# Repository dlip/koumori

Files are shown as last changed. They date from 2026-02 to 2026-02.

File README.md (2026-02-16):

# Koumori Keyboard

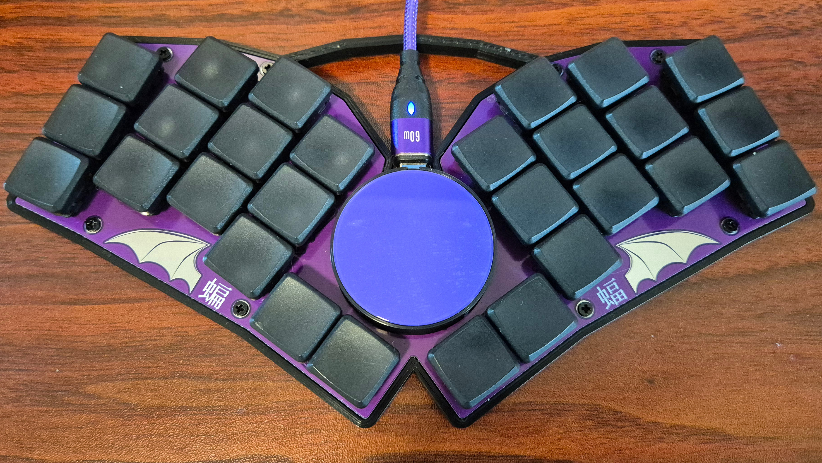
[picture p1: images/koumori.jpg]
Koumori


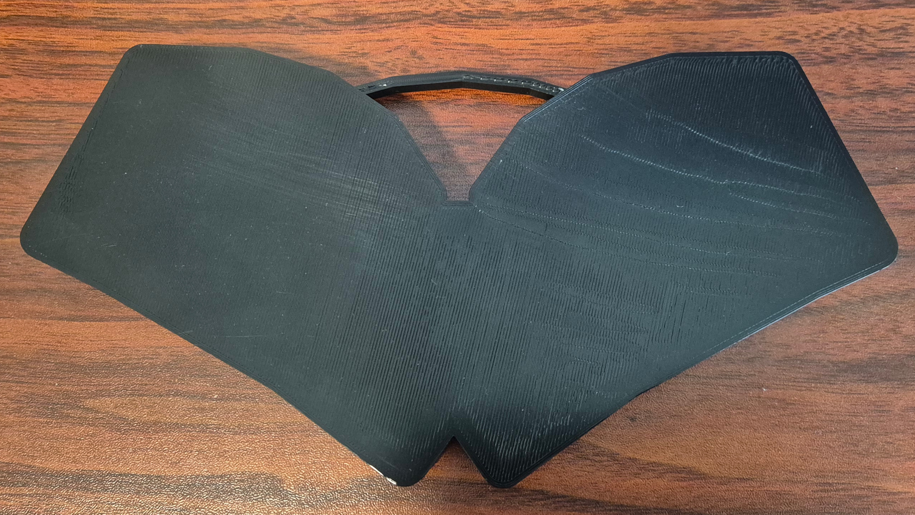
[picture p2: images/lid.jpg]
Lid


- Designed to be minimalistic and portable
- 28 keys (Using Engram with my [layout](https://github.com/dlip/qmk_firmware/blob/dlip/keyboards/dlip/koumori/keymaps/engram/README.md))
- Unibody design
- RP2040-Zero MCU
- Cirque 40mm trackpad with glass overlay
- Customizable layout with QMK Firmware
- Case with handle and magnetic lid
- PCB and case designed in [Ergogen](https://ergogen.xyz)
- Simple [build guide](./build.md) with no microscopic parts
- Name means the animal "bat" in Japanese
- Open source and free (GPL-3.0)

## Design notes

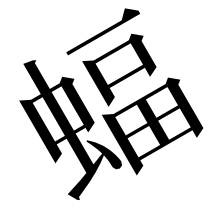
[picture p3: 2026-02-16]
kicad/footprints/text276.png

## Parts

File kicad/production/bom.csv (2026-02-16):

Designator | Footprint | Quantity | Value | LCSC Part #
D1, D10, D11, D12, D13, D14, D15, D16, D17, D18, D19, D2, D20, D21, D22, D23, D24, D25, D26, D27, D28, D3, D4, D5, D6, D7, D8, D9 | ComboDiode | 28
POINTING1 | Pointing-connector | 1
RP2040ZERO1 | RP2040-Zero | 1
S1, S10, S11, S12, S13, S14, S15, S16, S17, S18, S19, S2, S20, S21, S22, S23, S24, S25, S26, S27, S28, S3, S4, S5, S6, S7, S8, S9 | PG1350 | 28
_1, _10, _11, _2, _3, _4, _5, _6, _7, _8, _9 | MountingHole_2.2mm_M2_Pad_Via | 11

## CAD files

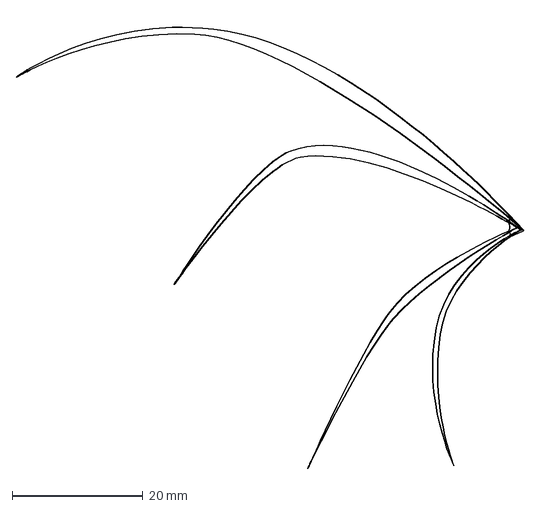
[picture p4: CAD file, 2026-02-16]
3d/wing.dxf
77.5 x 69.1 mm

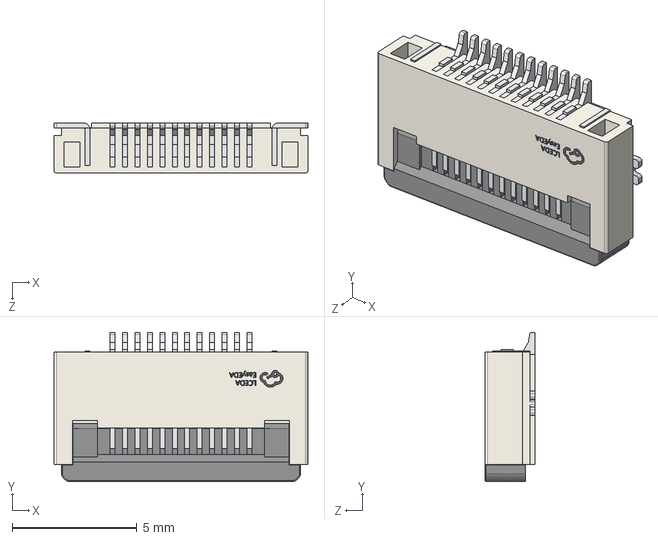
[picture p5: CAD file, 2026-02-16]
kicad/3dmodels/AFC01-S12FCC-00.step
10.2 x 6.00 x 2.01 mm

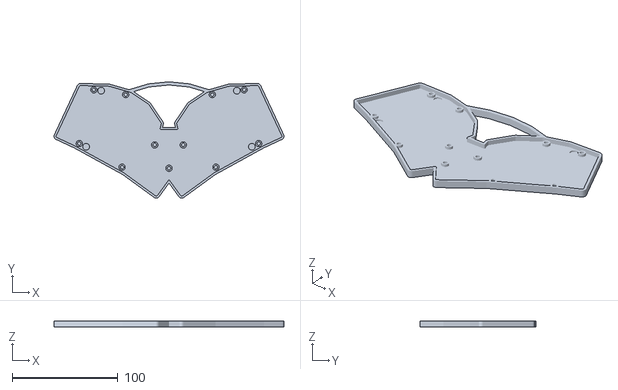
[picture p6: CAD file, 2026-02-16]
3d/case.stl
217.0 x 109.8 x 5.60

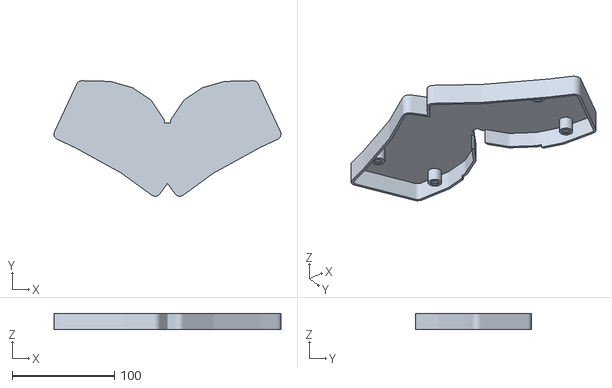
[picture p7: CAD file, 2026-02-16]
3d/lid.stl
221.6 x 112.8 x 16.0

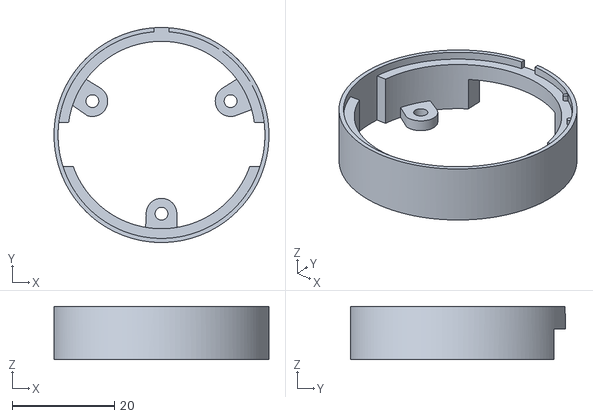
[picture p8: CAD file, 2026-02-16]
3d/cirque-mount.stl
42.0 x 42.0 x 10.4

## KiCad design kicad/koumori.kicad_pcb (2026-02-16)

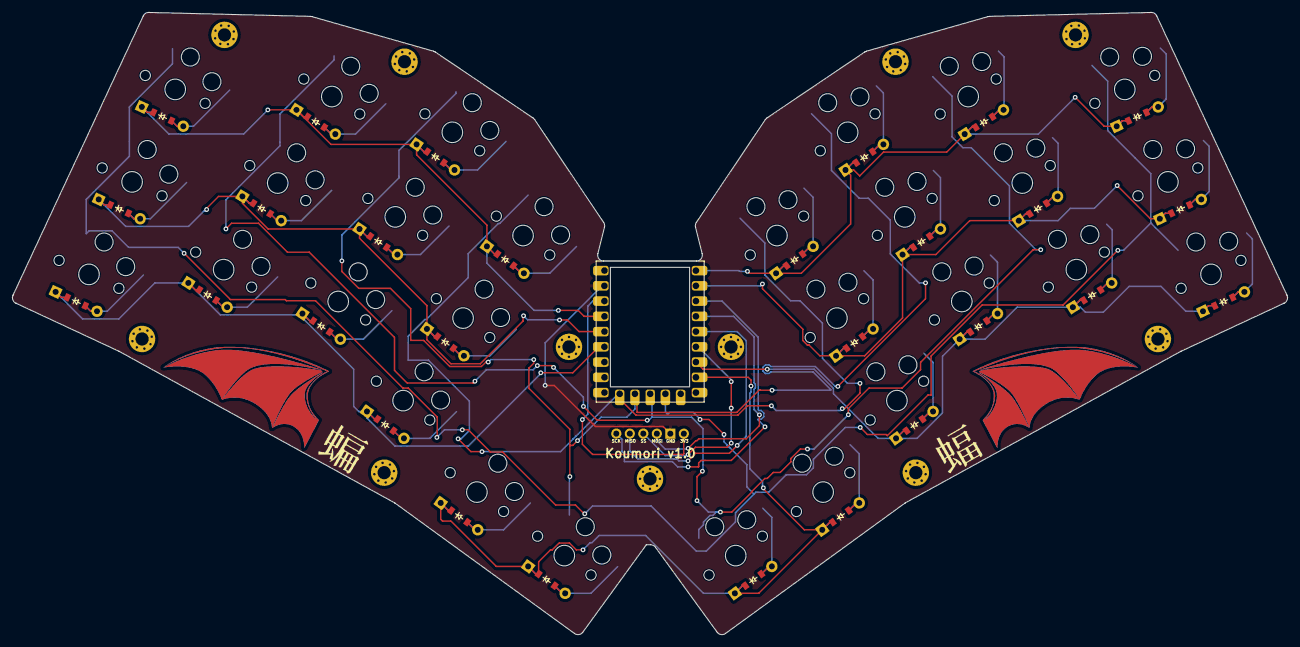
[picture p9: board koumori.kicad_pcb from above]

Board: 2 copper layers, 212.4 x 103.7 mm, 69 parts (0 on the bottom side), 45 nets.

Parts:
D1, D2, D3, D4, D5, D6, D7, D8, D9, D10, D11, D12, D13, D14, D15, D16, D17, D18, D19, D20, D21, D22, D23, D24, D25, D26, D27, D28: ComboDiode
Pointing1: Pointing-connector
RP2040Zero1: RP2040-Zero
S1, S2, S3, S4, S5, S6, S7, S8, S9, S10, S11, S12, S13, S14, S15, S16, S17, S18, S19, S20, S21, S22, S23, S24, S25, S26, S27, S28: PG1350
_1, _2, _3, _4, _5, _6, _7, _8, _9, _10, _11: MountingHole_2.2mm_M2_Pad_Via

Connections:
GND: Pointing1.5, RP2040Zero1.20
GP0: D17.1, D20.1, D23.1, D26.1, RP2040Zero1.1
GP1: D16.1, D19.1, D22.1, D25.1, RP2040Zero1.2
GP2: Pointing1.1, RP2040Zero1.3
GP3: Pointing1.4, RP2040Zero1.4
GP4: Pointing1.2, RP2040Zero1.5
GP5: Pointing1.3, RP2040Zero1.6
GP6: D15.1, D18.1, D21.1, D24.1, RP2040Zero1.7
GP7: D13.1, D14.1, D27.1, D28.1, RP2040Zero1.8
GP10: RP2040Zero1.11, S1.1, S2.1, S3.1, S15.1, S16.1, S17.1, S27.1
GP11: RP2040Zero1.12, S4.1, S5.1, S6.1, S18.1, S19.1, S20.1, S28.1
GP12: RP2040Zero1.13, S7.1, S8.1, S9.1, S14.1, S21.1, S22.1, S23.1
GP13: RP2040Zero1.14, S10.1, S11.1, S12.1, S13.1, S24.1, S25.1, S26.1
GP27: D1.1, D4.1, D7.1, D10.1, RP2040Zero1.18
GP28: D2.1, D5.1, D8.1, D11.1, RP2040Zero1.22
GP29: D3.1, D6.1, D9.1, D12.1, RP2040Zero1.23
P3V3: Pointing1.6, RP2040Zero1.21
index_bottom: D10.2, S10.2
index_middle: D11.2, S11.2
index_top: D12.2, S12.2
inner_top: D13.2, S13.2
middle_bottom: D7.2, S7.2
middle_middle: D8.2, S8.2
middle_top: D9.2, S9.2
mirror_index_bottom: D24.2, S24.2
mirror_index_middle: D25.2, S25.2
mirror_index_top: D26.2, S26.2
mirror_inner_top: D27.2, S27.2
mirror_middle_bottom: D21.2, S21.2
mirror_middle_middle: D22.2, S22.2
mirror_middle_top: D23.2, S23.2
mirror_outer_top: D28.2, S28.2
mirror_pinky_bottom: D15.2, S15.2
mirror_pinky_middle: D16.2, S16.2
mirror_pinky_top: D17.2, S17.2
mirror_ring_bottom: D18.2, S18.2
mirror_ring_middle: D19.2, S19.2
mirror_ring_top: D20.2, S20.2
outer_top: D14.2, S14.2
pinky_bottom: D1.2, S1.2
pinky_middle: D2.2, S2.2
pinky_top: D3.2, S3.2
ring_bottom: D4.2, S4.2
ring_middle: D5.2, S5.2
ring_top: D6.2, S6.2

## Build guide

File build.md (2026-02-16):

# Build

## BOM

| Name | Qty | Link |
| --- | --- | --- |
| PCB (kicad/production/koumori_v1.0.0.zip) | 1 | <https://jlcpcb.com/> |
| Cirque 40mm Trackpad TM040040-2024-302 with flat overlay | 1 | <https://au.mouser.com/ProductDetail/Cirque/TM040040-2024-302> |
| Choc v1 Switches | 28  | <https://keebd.com/products/ambients-silent-linear-nocturnal-choc-switches> |
| Choc v1 Keycaps | 28  | <https://chosfox.com/collections/cfx-keycaps/products/chocfox-cfx-choc-keycaps> |
| RP2040 Zero MCU | 1 | <https://www.aliexpress.com/item/1005007650325892.html> |
| 1N4148W diodes | 28  | <https://www.aliexpress.com/item/4000685043735.html> |
| Choc v1 Hot-Swap Socket (Low Profile) | 28  | <https://www.aliexpress.com/item/1005006625852715.html> Note: these ones had a slightly annoying to solder metal tab |
| M2 Screw 4mm | 8 | <https://www.aliexpress.com/item/4001248931159.html> |
| M2 Screw 6mm | 3 | <https://www.aliexpress.com/item/4001248931159.html> |
| M2 knurled insert nuts 3mm length 3.5mm OD | 11  | <https://www.aliexpress.com/item/1005008897571758.html> |
| Neodymium Magnets 6mm x 3mm | 8 | <https://www.aliexpress.com/item/1005010074888189.html> |
| Wire (30 AWG) | 1 | <https://www.aliexpress.com/item/1005007256968315.html> |
| Adhesive Vinyl Sheets | 1 | <https://www.aliexpress.com/item/1005009732820762.html> |
| 40mm Glass Smartwatch Screen Protector (**NOT** Galaxy Watch 40mm which is actually 36.5mm) | 1 | <https://www.aliexpress.com/item/1005007458477781.html> |
| USB-C Cable | 1 | <https://www.aliexpress.com/item/1005005931593343.html> |
| Blutak | 1 | |
| Superglue | 1 | |
| 3D Printed Case (3d/case.stl) | 1 | |
| 3D Printed Lid (3d/lid.stl) | 1 | |
| 3D Printed Cirque Mount (3d/cirque-mount.stl) | 1 | |

## Build

- Flash the firmware first to make sure your MCU is ok <https://github.com/dlip/qmk_firmware/tree/dlip/keyboards/dlip/koumori>
- Tin the left side of all the pads on the back (side containing the url)

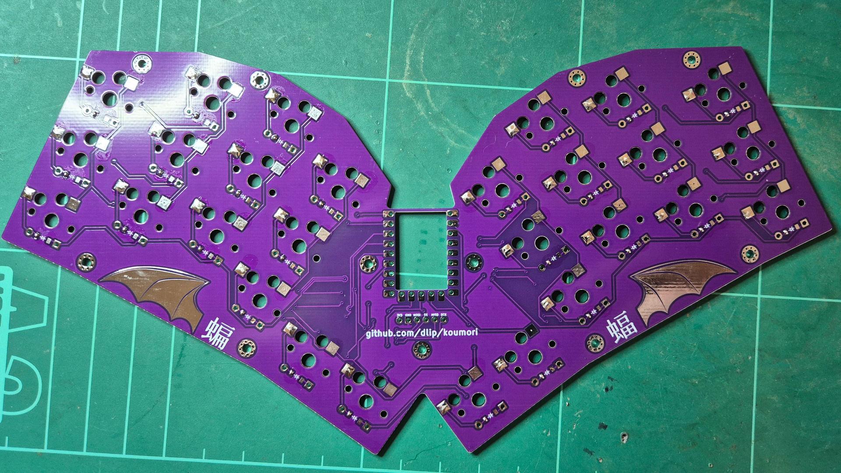
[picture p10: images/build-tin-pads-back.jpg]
Tin pads back


- Before soldering, note the correct direction of the diodes following the side with the line

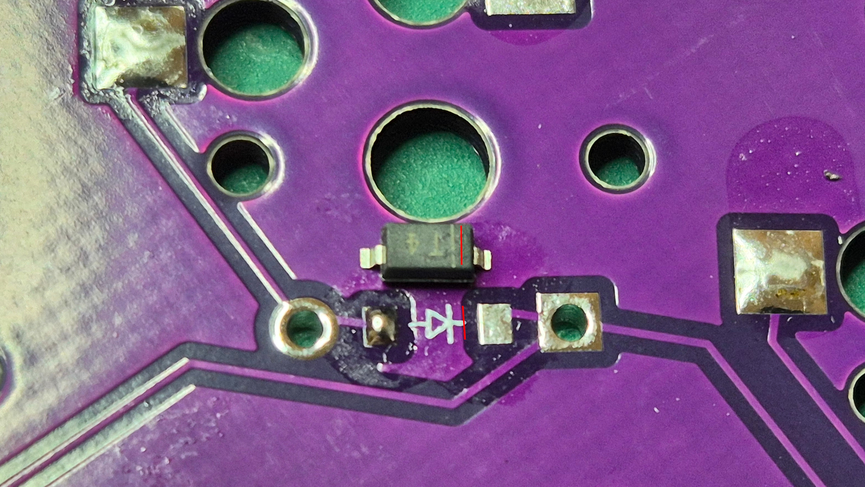
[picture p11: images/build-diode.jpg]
Diodes


- Solder the left side of the diodes and hot swap sockets, ensuring they are aligned, then solder the right sides. Note: I was short on hot swap sockets here, so some are missing

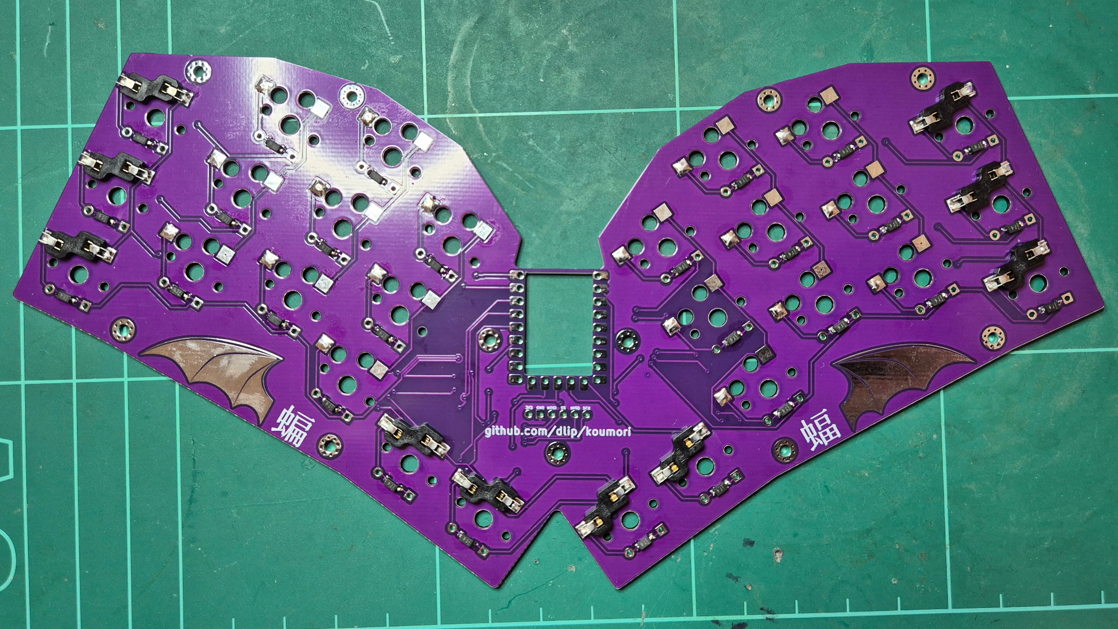
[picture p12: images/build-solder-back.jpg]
Solder Back


- Flip over to the front side
- Tin the pads for the MCU

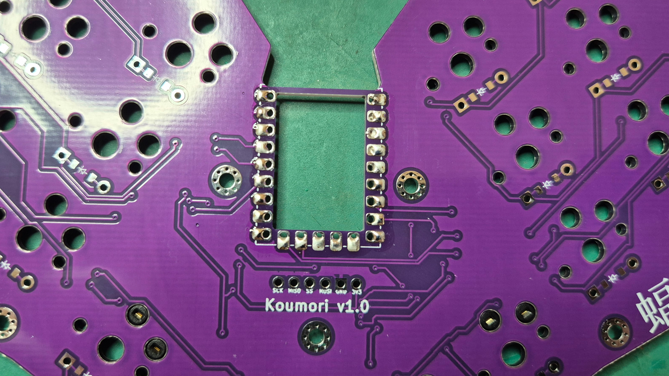
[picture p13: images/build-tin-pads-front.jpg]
Tin pads front


- Solder one pin on the MCU and ensure it is aligned perfectly
- Solder the pin on the opposite corner to ensure it won't move
- Solder the remaining pins

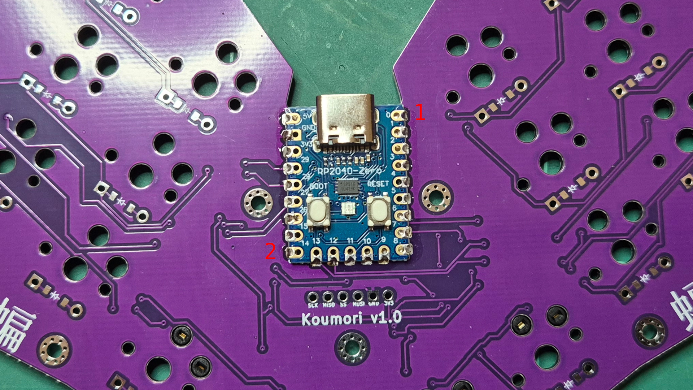
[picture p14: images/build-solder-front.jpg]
Solder front


- Peel off stock overlay from Cirque
- Stick glass protector to vinyl sheet
- Cut out using scissors and a X-Acto knife
- Stick on Cirque

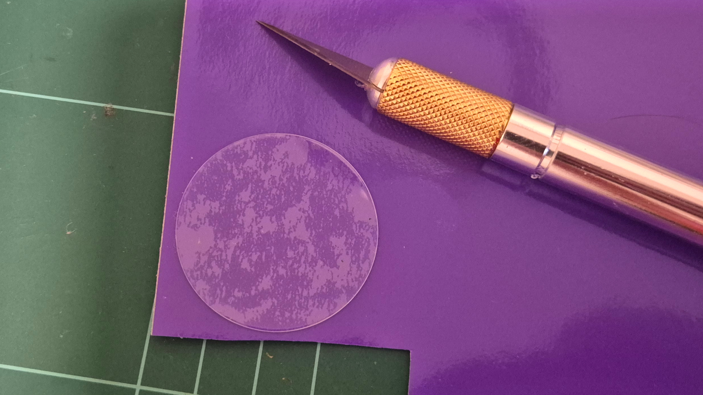
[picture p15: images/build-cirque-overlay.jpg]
Cirque overlay


- Solder Cirque using about 10 cm wire stripped at the ends using the following mapping
  - SCK -> SCK
  - MISO -> SO
  - SS -> SS
  - MOSI -> SI
  - GND -> GND
  - 3V3 -> VDD

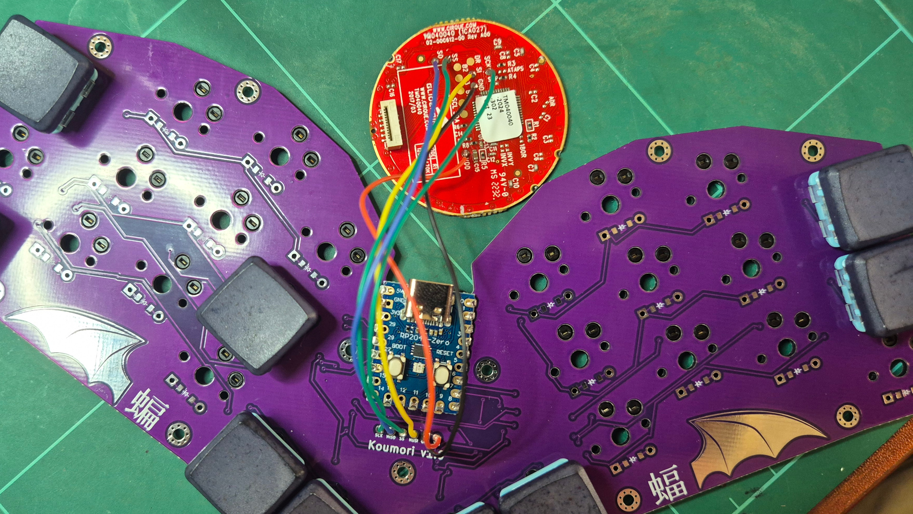
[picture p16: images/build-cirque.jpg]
Cirque


- Add switches and keycaps
- Connect USB and test everything is working
- Melt knurled nuts into base with soldering iron at around 180c
- Mark the side of the magnets you intend to point upwards
- Superglue magnets into base, ensuring your mark **IS** showing

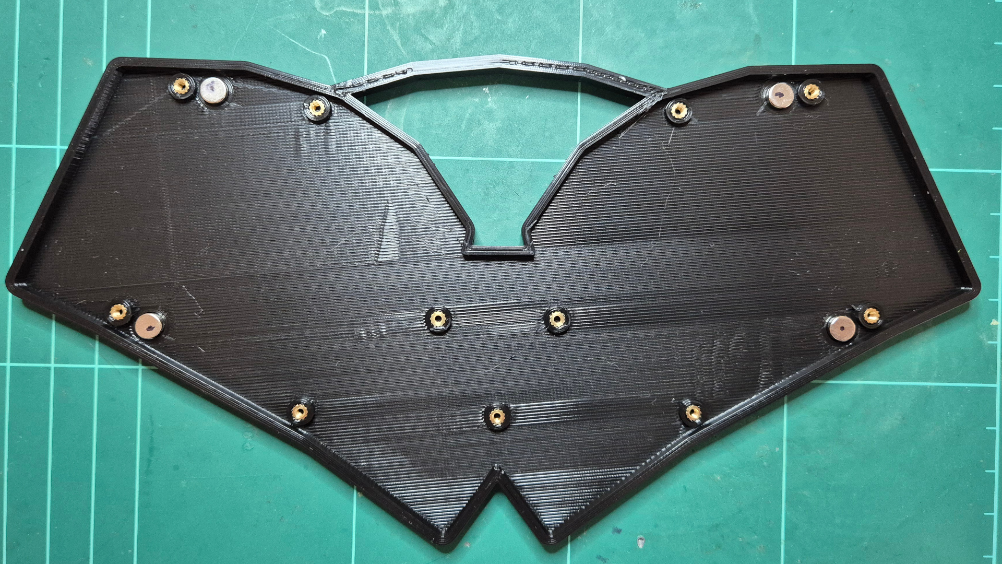
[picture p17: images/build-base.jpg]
Base


- Screw 3x6mm screws in the center region and 8x4mm in the remaining holes

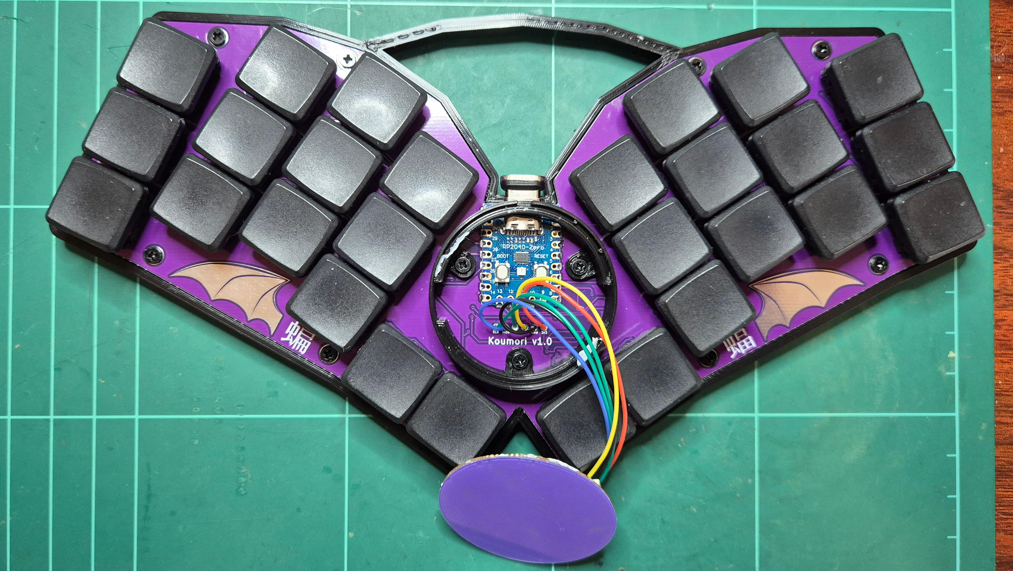
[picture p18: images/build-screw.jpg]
Screw


- Add rubber feet

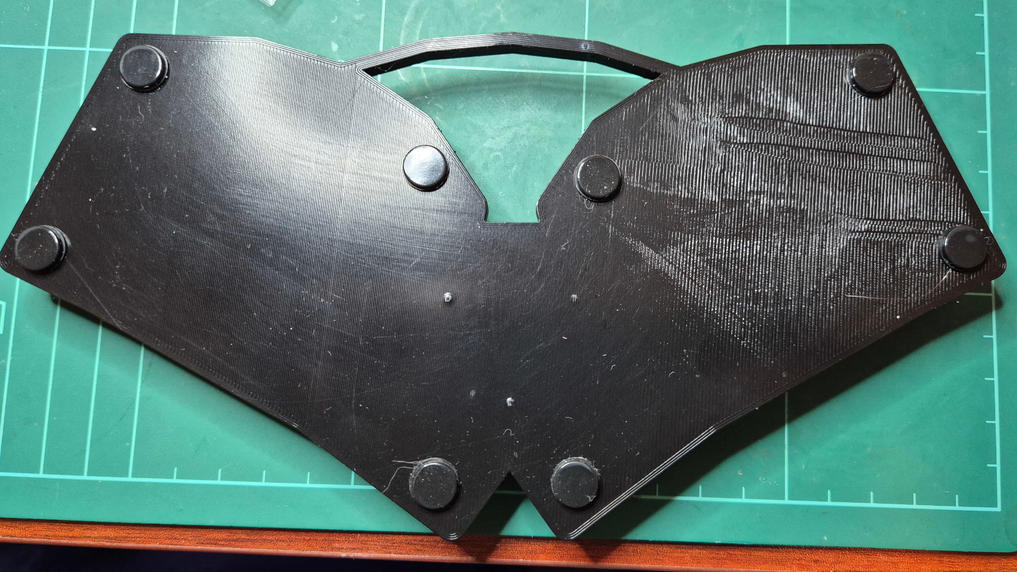
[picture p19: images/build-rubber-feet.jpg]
Rubber feet


- Superglue magnets into lid, ensuring your mark **IS NOT** showing

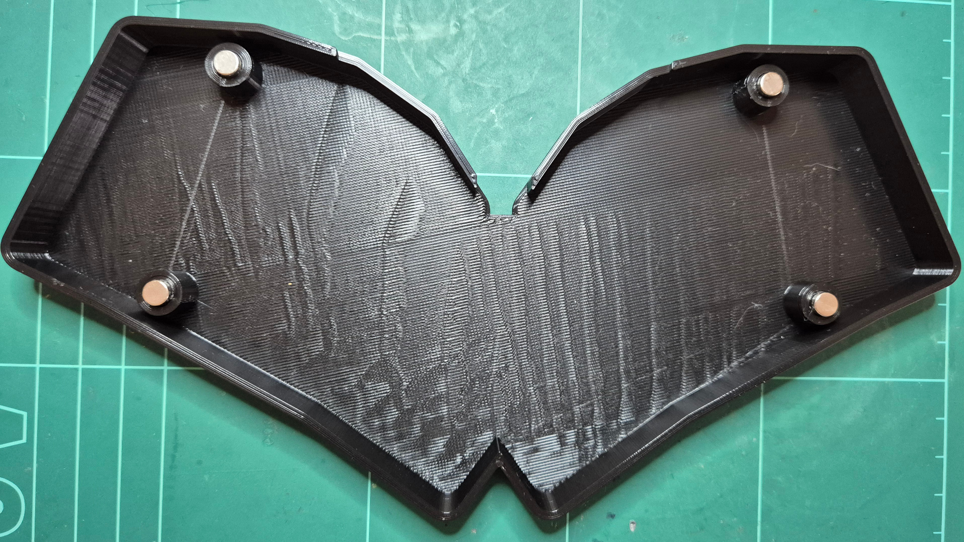
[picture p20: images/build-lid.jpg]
Lid


- Add a small amount of Blutak to keep the Cirque from moving and push it down, ensuring the 2 notches match in the top right

- Done!

Koumori

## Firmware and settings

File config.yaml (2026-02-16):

units:
  # Proxy Spacing Variables
  kx: cx
  ky: cy
  # Padding Variables
  px: kx + 2
  py: ky + 2
  # M2 Screw Inserts
  screwRadius: 1.70
  standoffRadius: 3
  # Footprints
  rp2040zero_x: 18
  rp2040zero_y: 23.5
  pointing_x: 13
  pointing_y: 3
  # Case
  standoffHeight: 3.4
  pcbThickness: 1.6
  wallThickness: 2
  wallTollerance: 0.3
  handleRadius: 100
  handleThickness: 3
  magnetHeight: 3.3
  magnetRadius: 3.2
  keyHeight: 12
  hotSwapMaxHeight: 2
  caseHeight: wallThickness + hotSwapMaxHeight + pcbThickness
points:
  zones:
    matrix:
      mirror: &mirror
        ref: matrix_index_top
        distance: 42.3
      anchor:
        shift: [30, -80]
      key:
        padding: 1ky
        spread: 1kx
      columns:
        pinky:
          key:
            splay: -25
            column_net: GP10
            mirror.column_net: GP10
        ring:
          key:
            stagger: 0.6ky
            splay: -7
            spread: 1kx + 2
            column_net: GP11
            mirror.column_net: GP11
        middle:
          key:
            stagger: 0.33ky
            splay: -2
            spread: 1kx + 1
            column_net: GP12
            mirror.column_net: GP12
        index:
          key:
            stagger: -0.45ky
            splay: -2
            spread: 1kx + 0.2
            column_net: GP13
            mirror.column_net: GP13
      rows:
        bottom:
          row_net: GP27
          mirror.row_net: GP6
        middle:
          row_net: GP28
          mirror.row_net: GP1
        top:
          row_net: GP29
          mirror.row_net: GP0
    thumbs:
      mirror: *mirror
      key:
        padding: 1ky
        spread: 1kx
      anchor:
        ref: matrix_index_bottom
        shift: [1.05kx, -.3ky]
      columns:
        inner:
          key:
            splay: 0
            column_net: GP13
            mirror.column_net: GP10
        outer:
          key:
            column_net: GP12
            mirror.column_net: GP11
      rows:
        top:
          row_net: GP7
          mirror.row_net: GP7
    mcu:
      anchor:
        aggregate.parts: [matrix_index_top, mirror_matrix_index_top]
        shift: [0, -16]
    cirque:
      anchor:
        ref: [mcu]
        shift: [0, -9.4]
    pointing:
      anchor:
        ref: [mcu]
        shift: [0, -17]
    handle:
      anchor:
        ref: [mcu]
        shift: [0, -43]
    handleMask:
      anchor:
        ref: [handle]
        shift: [0, -45]
    holePinkyop:
      mirror: *mirror
      anchor:
        ref: [matrix_pinky_top]
        shift: [0.2kx, 0.65kx]
    holeRingTop:
      mirror: *mirror
      anchor:
        ref: [matrix_ring_top]
        shift: [0.4kx, 0.63kx]
    holeRingBottom:
      mirror: *mirror
      anchor:
        ref: [matrix_ring_bottom]
        shift: [-0.3kx, -1ky]
    holeOuterThumbs:
      mirror: *mirror
      anchor:
        ref: [matrix_index_bottom]
        shift: [.25kx, -0.68ky]
    holeBottom:
      anchor:
        ref: [mcu]
        shift: [0kx, -1.443ky]
    holeLeft:
      mirror: *mirror
      anchor:
        ref: [mcu]
        shift: [-.75kx, -.15ky]
    magnetsBottom:
      mirror: *mirror
      anchor:
        ref: [matrix_ring_bottom]
        shift: [.09kx, -0.95ky]
    magnetsTop:
      mirror: *mirror
      anchor:
        ref: [matrix_ring_top]
        shift: [-.8kx, .13ky]
    usbCutout:
      anchor:
        ref: [mcu]
        shift: [0, 13]
    lidMask:
      anchor:
        ref: [mcu]
        shift: [0, 35]
outlines:
  keys:
    - what: rectangle
      where: /matrix|thumb/
      size: [kx-0.5, ky-0.5]
  board:
    - what: polygon
      operation: stack
      fillet: 1
      points:
        - ref: matrix_pinky_top
          shift: [-0.5px, 0.5py]
        - ref: matrix_ring_top
          shift: [-0.5px, 0.5py]
        - ref: matrix_middle_top
          shift: [-0.5px, 0.5py]
        - ref: matrix_middle_top
          shift: [0.5px, 0.5py]
        - ref: matrix_index_top
          shift: [0.5px, 0.5py]
        - ref: mcu
          shift: [-rp2040zero_x/2, rp2040zero_y/2]
        - ref: mcu
          shift: [rp2040zero_x/2, rp2040zero_y/2]
        - ref: mirror_matrix_index_top
          shift: [0.5px, 0.5py]
        - ref: mirror_matrix_middle_top
          shift: [0.5px, 0.5py]
        - ref: mirror_matrix_middle_top
          shift: [-0.5px, 0.5py]
        - ref: mirror_matrix_ring_top
          shift: [-0.5px, 0.5py]
        - ref: mirror_matrix_pinky_top
          shift: [-0.5px, 0.5py]
        - ref: mirror_matrix_pinky_bottom
          shift: [-0.5px, -0.5py]
        - ref: mirror_matrix_pinky_bottom
          shift: [0.5px, -0.5py]
        - ref: mirror_thumbs_inner_top
          shift: [-0.5px, -0.5py]
        - ref: mirror_thumbs_outer_top
          shift: [0.5px, -0.5py]
        - ref: mirror_thumbs_outer_top
          shift: [0.5px, 0.5py]
        - ref: mirror_thumbs_outer_top
          shift: [0.5px, 0.5py]
        - ref: thumbs_outer_top
          shift: [0.5px, 0.5py]
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

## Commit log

2026-02-16 Koumori v1.0
    [AFC01-S12FCC-00.step, bom.csv, case.stl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]
2026-02-16 Add magnet link
